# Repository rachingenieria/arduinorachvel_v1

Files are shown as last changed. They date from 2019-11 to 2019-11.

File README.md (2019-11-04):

# arduinorachvel_v1
Codigo de Velocista de JJtronics

Este repositorio contiene los archivos basicos para implementar el velocista ARDUINORACH V1

Contine:
Documentos de especificaciones

Firmware: Codigo fuente de Velocista con PID ARDUINORACH_V7
Copia de la Libreria Adafruit_SSD1306-master.zip para instalar en Arduino
como instalar: ARDUINO - Programa Menu -> Incluir Libreria -> Añadir Bliblioteca Zip

APP:Aplicativo Android
3D:Soporte de la BAteria y bomper para sensores frontal

RACHINGENIERIA

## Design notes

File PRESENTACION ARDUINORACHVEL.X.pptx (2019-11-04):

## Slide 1

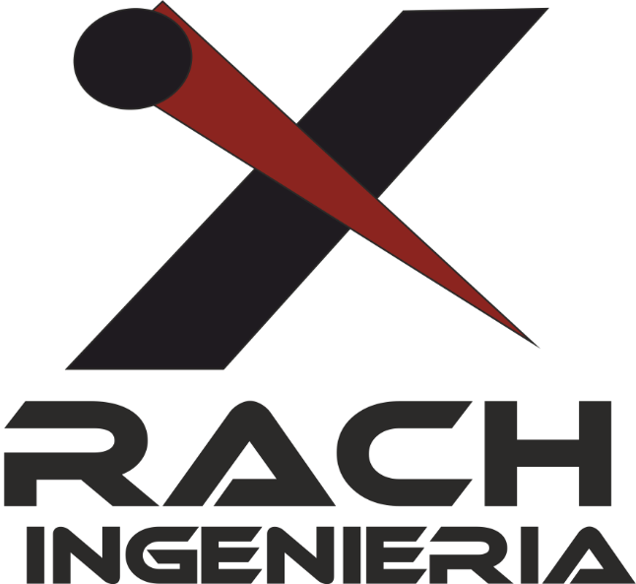
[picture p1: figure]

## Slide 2

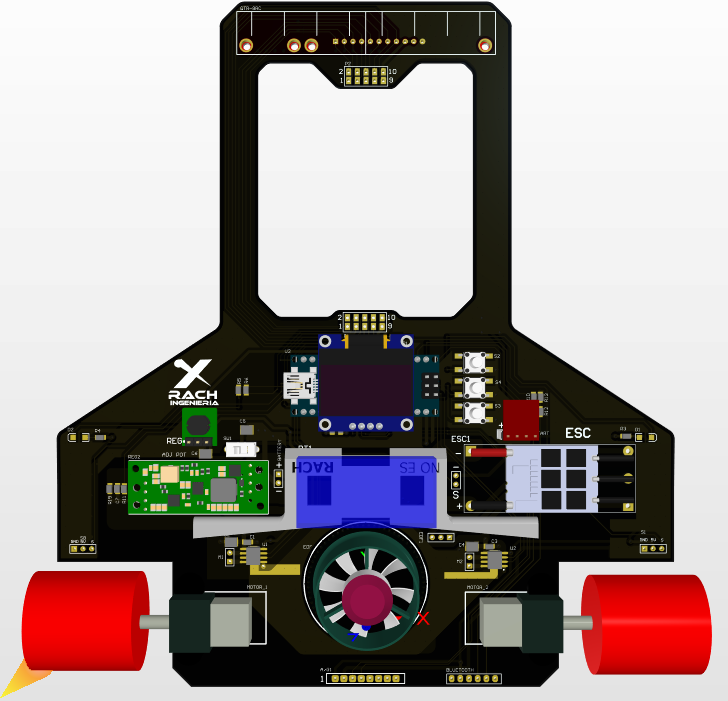
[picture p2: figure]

VELOCISTA PROFESIONAL
Descripción:
Versión Básica:
- PCB de doble marca RACHINGENIERIA
- ARDUINO NANO
- Sensores QRT8 Pololu DIGITALES
- Regulador 5V 1A
- Puente H 36V 3.6A Canal
- Micromotores
- Batería 2s o 3S
- Llantas de Poliuretano
- Rin metálico de bajo perfil
marca RACHINGEIERIA
- Puerto para modulo de Arranque
Versión Profesional (se adiciona)
- Elevador de Voltaje hasta 25V
- ESC 10A
- Turbina EDF27
- Display Oled De configuración
- Tres pulsadores de Usuario
Opcionales
- Bluetooth HC05 o HC06
- IMU (Acelerómetro y Giroscopio)
- Sensores para NATCAR o Encoder
- Extensión de sensores

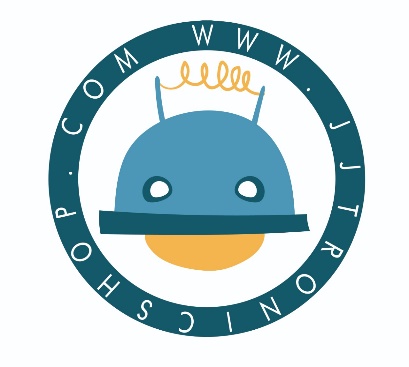
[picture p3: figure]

Cómpralo en:
www.jjtronicsshop.com

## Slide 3

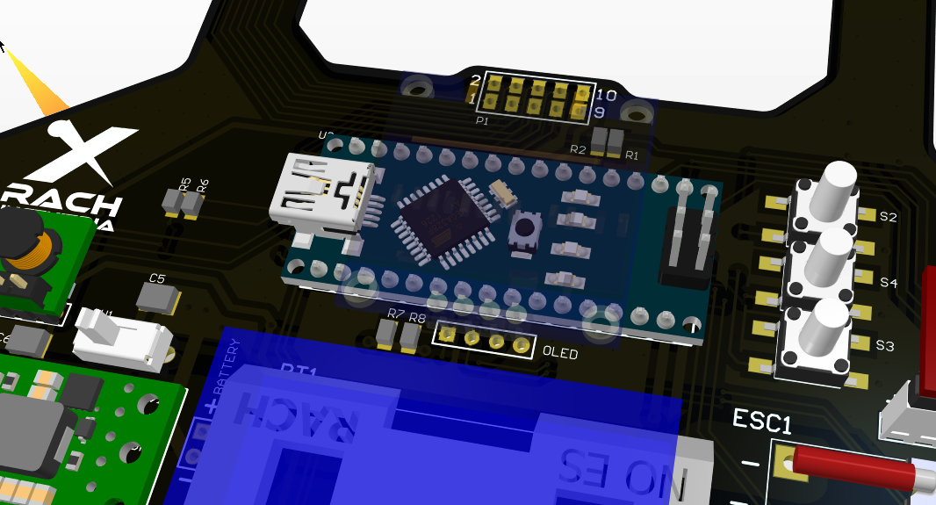
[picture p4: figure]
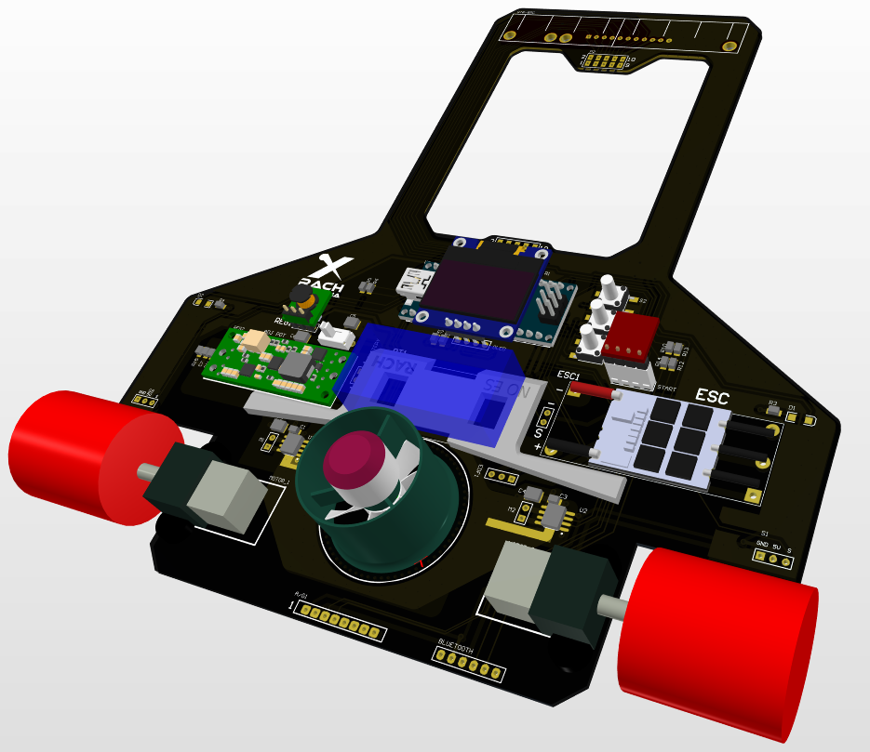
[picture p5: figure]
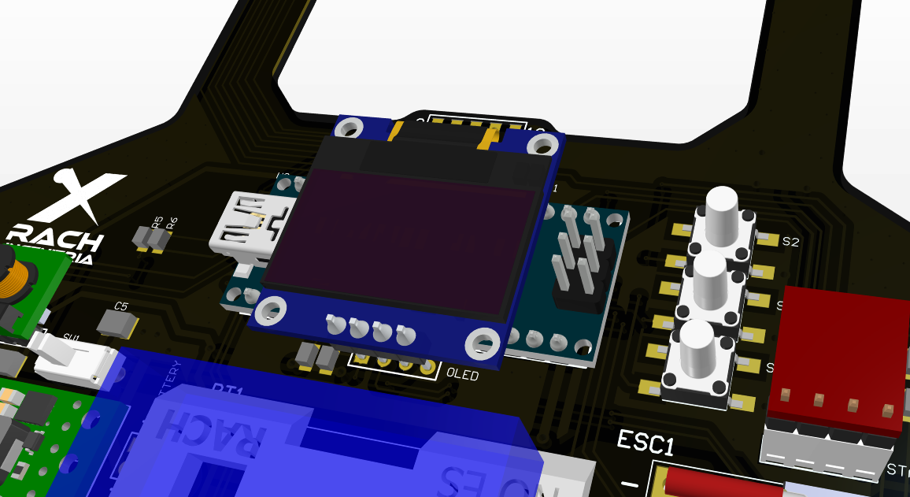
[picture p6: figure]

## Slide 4

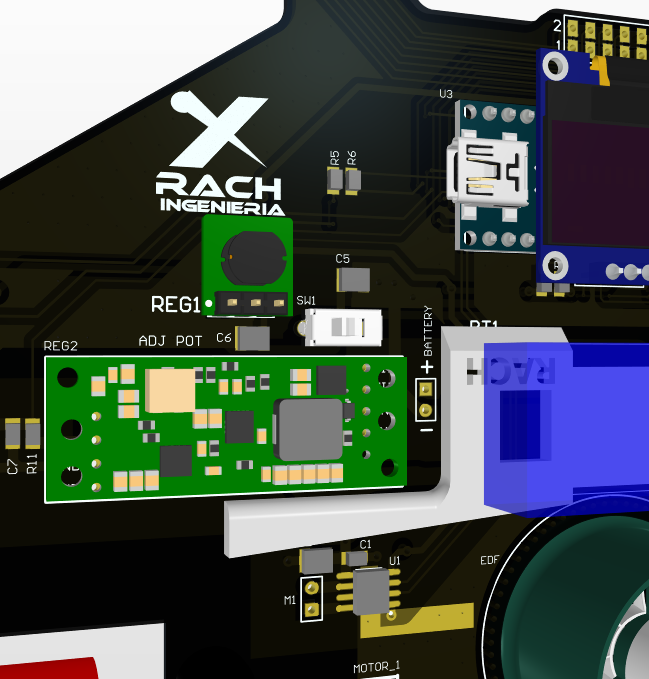
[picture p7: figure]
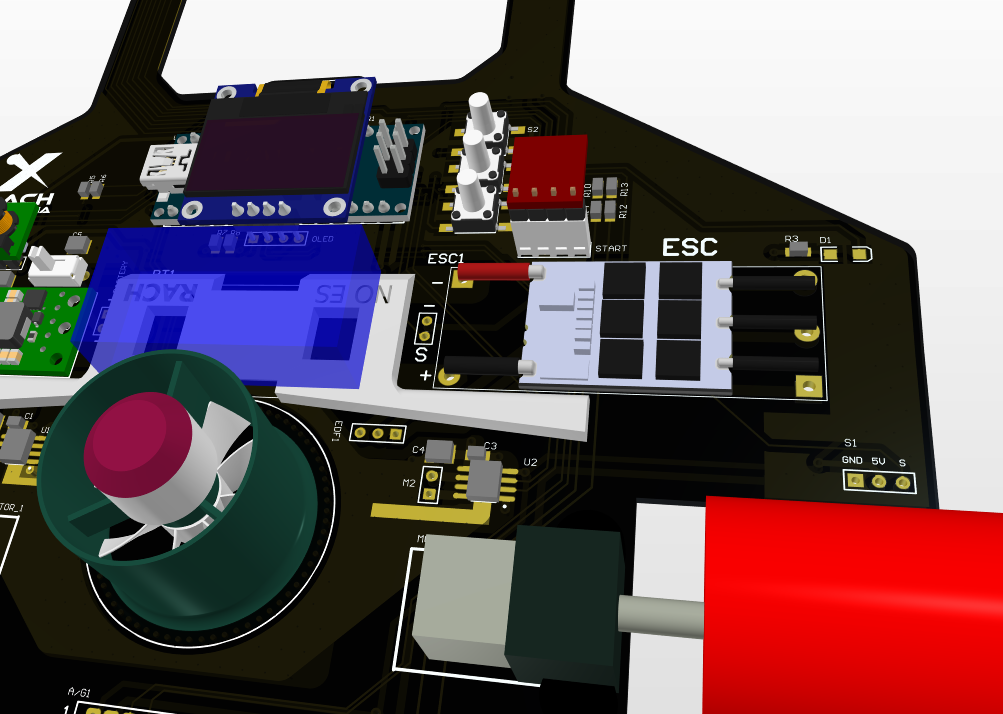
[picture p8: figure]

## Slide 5

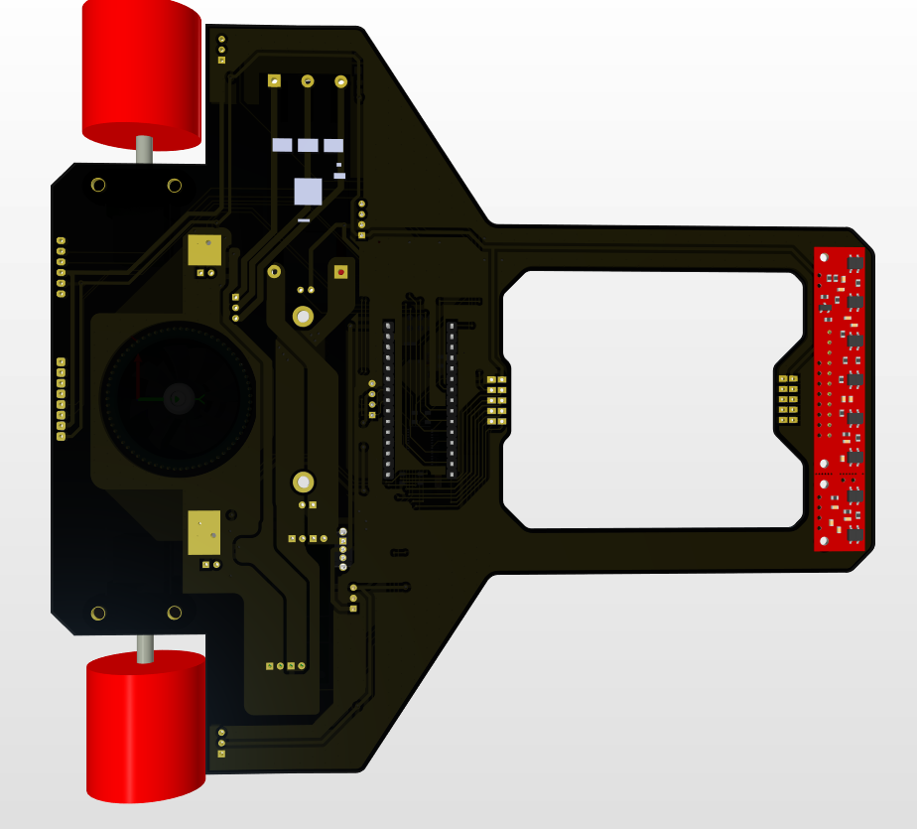
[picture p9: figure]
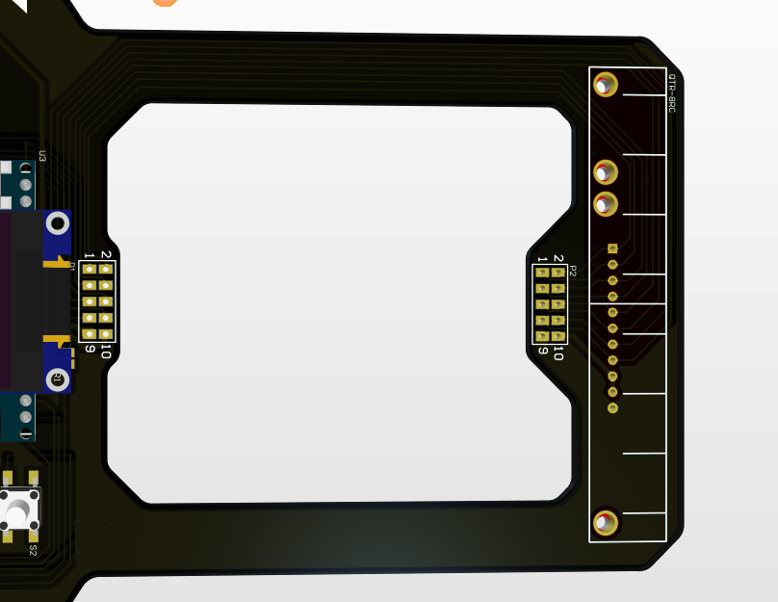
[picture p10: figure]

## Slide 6

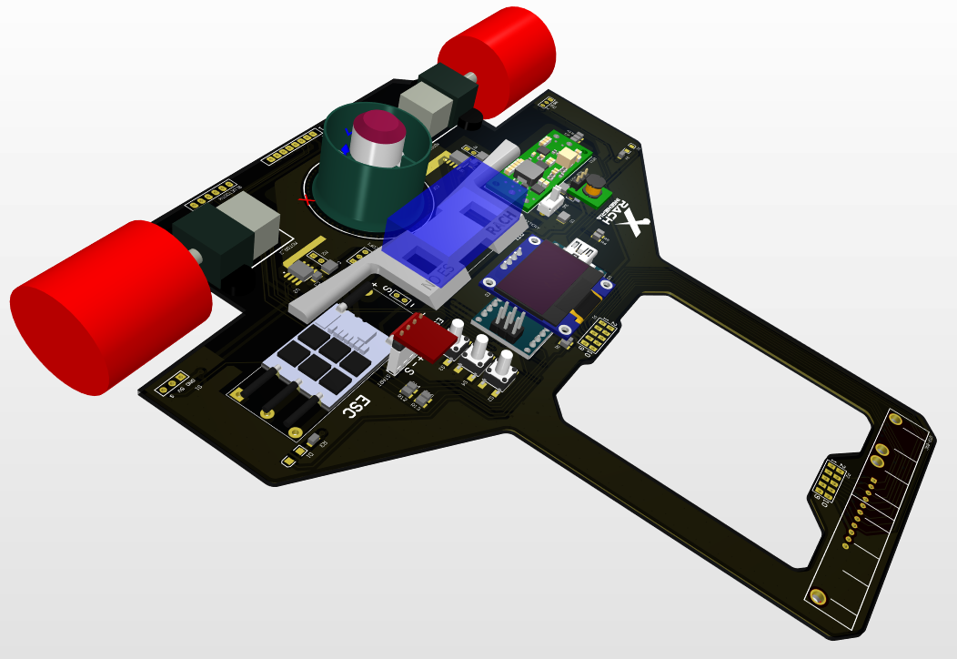
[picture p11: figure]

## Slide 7

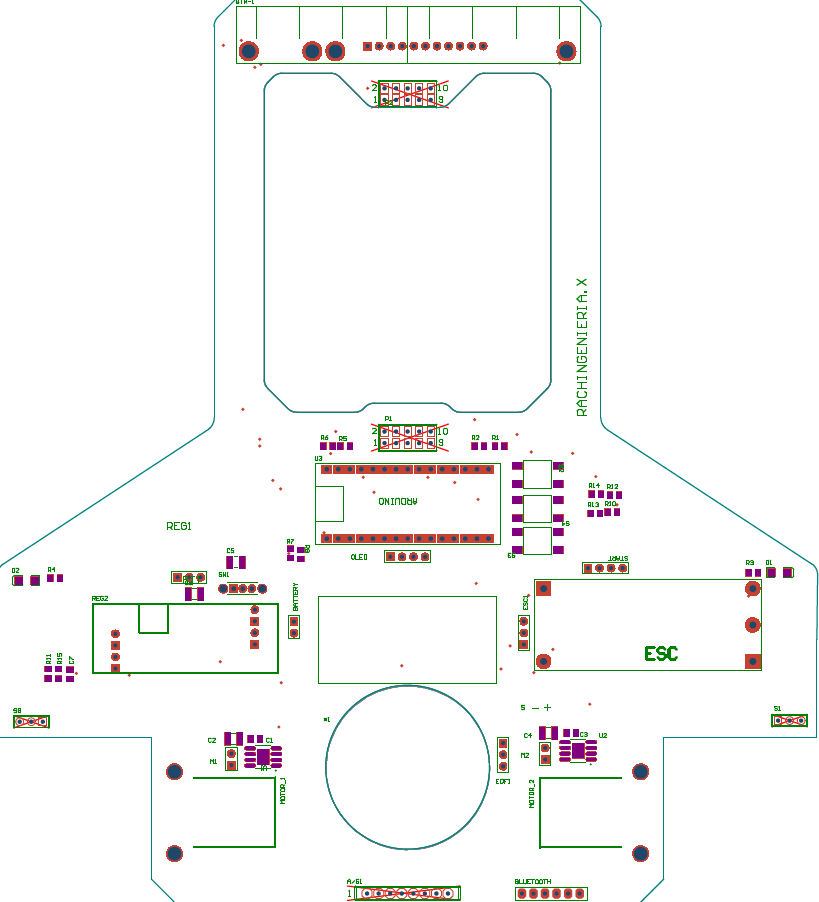
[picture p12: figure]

PARA VENTA DE PCB:
- PCB
- PLANO DE ARMADO
- CIRCUITO ESQUEMATICO
- LISTADO DE MATERIALES
- FIRMWARE ARDUIN0
- Aplicativo Android
- Soporte sensores 3D
- Bomper sensores frontales 3D

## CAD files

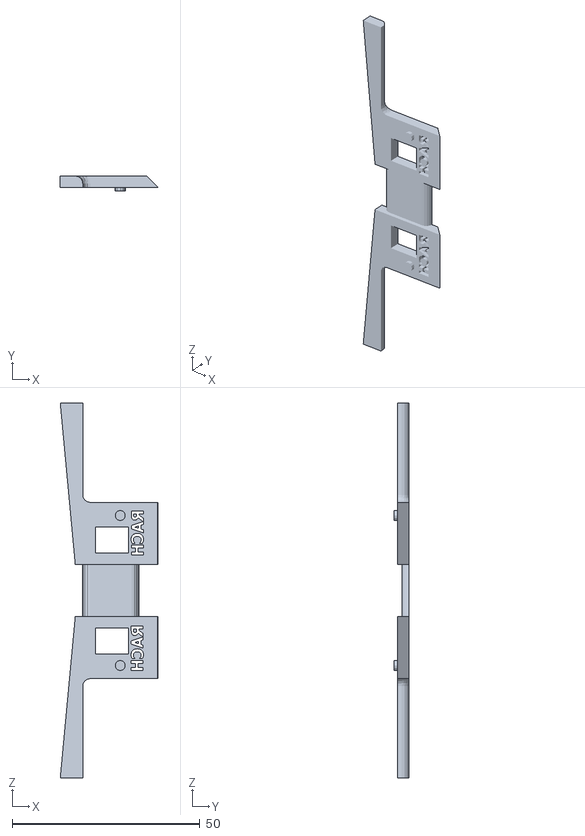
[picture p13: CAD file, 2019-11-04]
3D/soporteBat_V3.stl
26.0 x 4.00 x 100.0

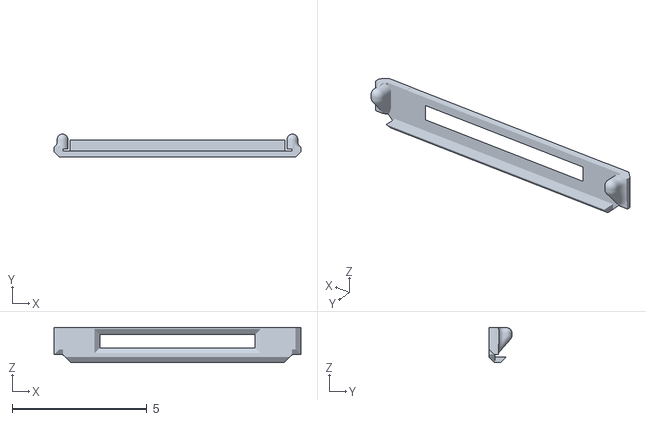
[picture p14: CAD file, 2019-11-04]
3D/PINVLECISTA.stl
9.16 x 0.849 x 1.31

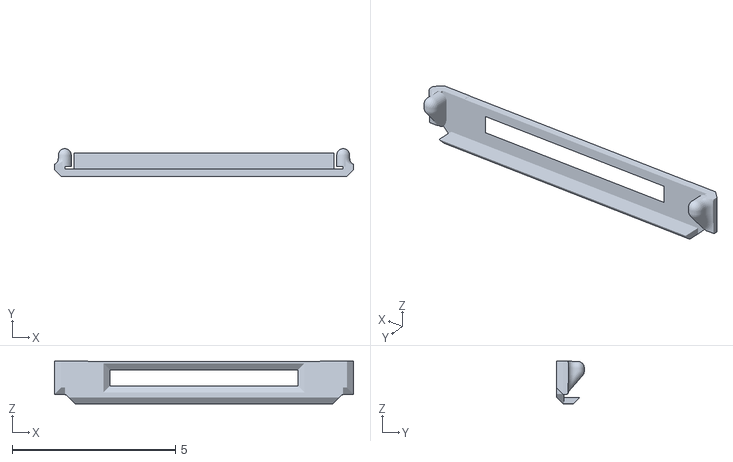
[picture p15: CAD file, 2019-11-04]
3D/PINVLECISTA.dwg.stl
9.16 x 0.849 x 1.31

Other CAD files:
3D/PINVLECISTA.ipt
3D/soporte_bat_rachx.ipt

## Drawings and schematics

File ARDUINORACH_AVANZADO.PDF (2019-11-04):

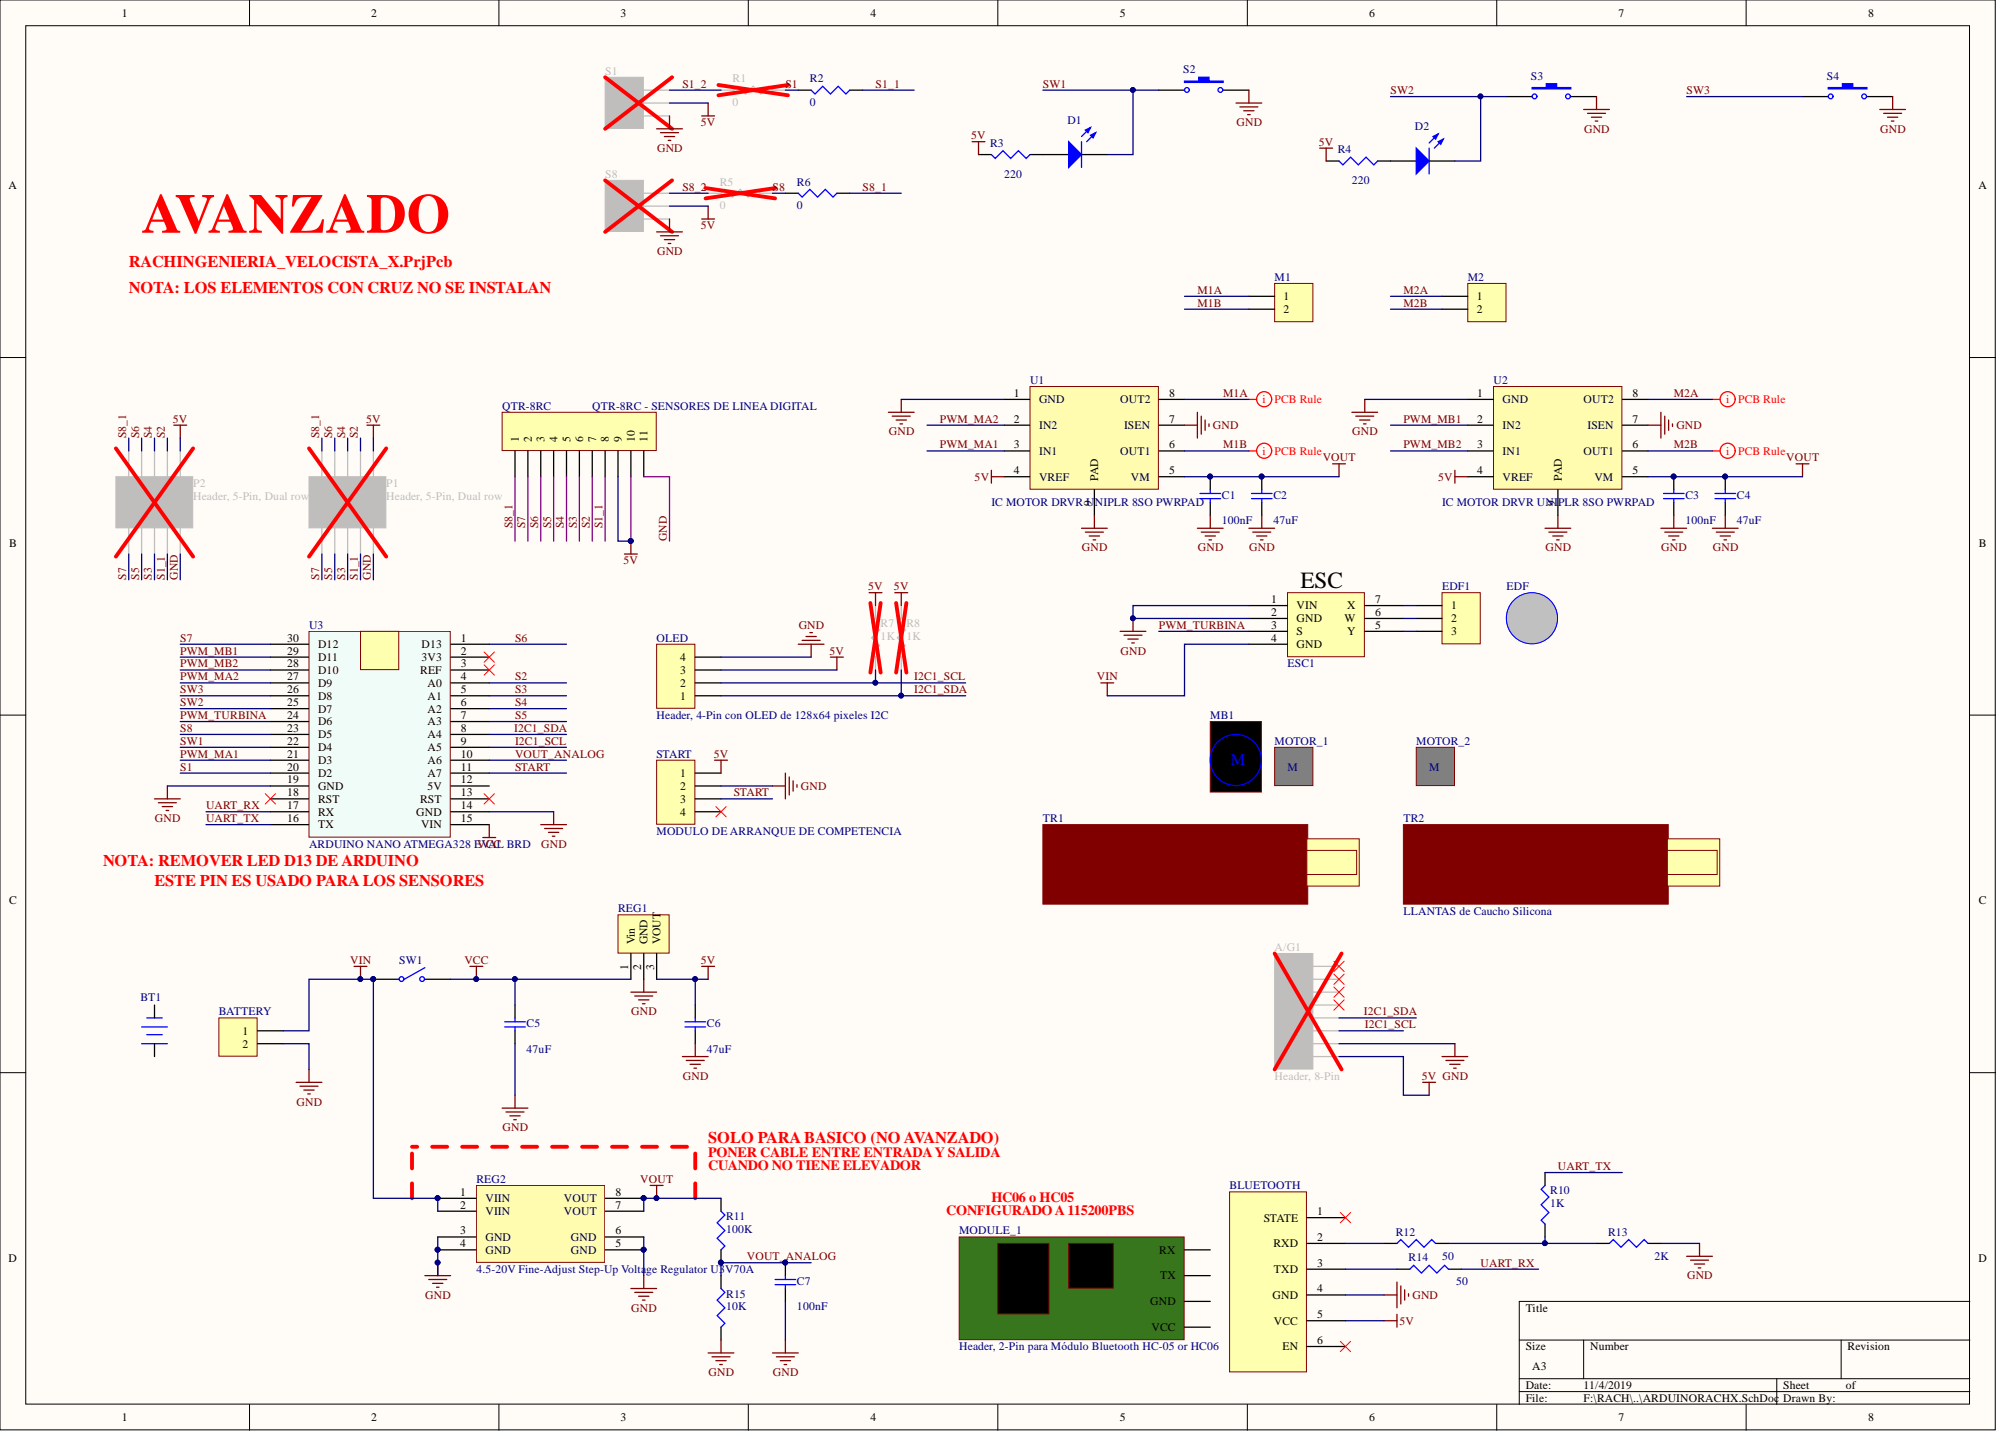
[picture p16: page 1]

RACHINGENIERIA_VELOCISTA_X.PrjPcb
NOTA: LOS ELEMENTOS CON CRUZ NO SE INSTALAN

Header, 5-Pin, Dual row

IC MOTOR DRVR UNIPLR 8SO PWRPAD

Header, 4-Pin con OLED de 128x64 pixeles I2C

ARDUINO NANO ATMEGA328 EVAL BRD

NOTA: REMOVER LED D13 DE ARDUINO

ESTE PIN ES USADO PARA LOS SENSORES

LLANTAS de Caucho Silicona

SOLO PARA BASICO (NO AVANZADO)
PONER CABLE ENTRE ENTRADA Y SALIDA
CUANDO NO TIENE ELEVADOR

4.5-20V Fine-Adjust Step-Up Voltage Regulator U3V70A

Header, 2-Pin para Módulo Bluetooth HC-05 or HC06

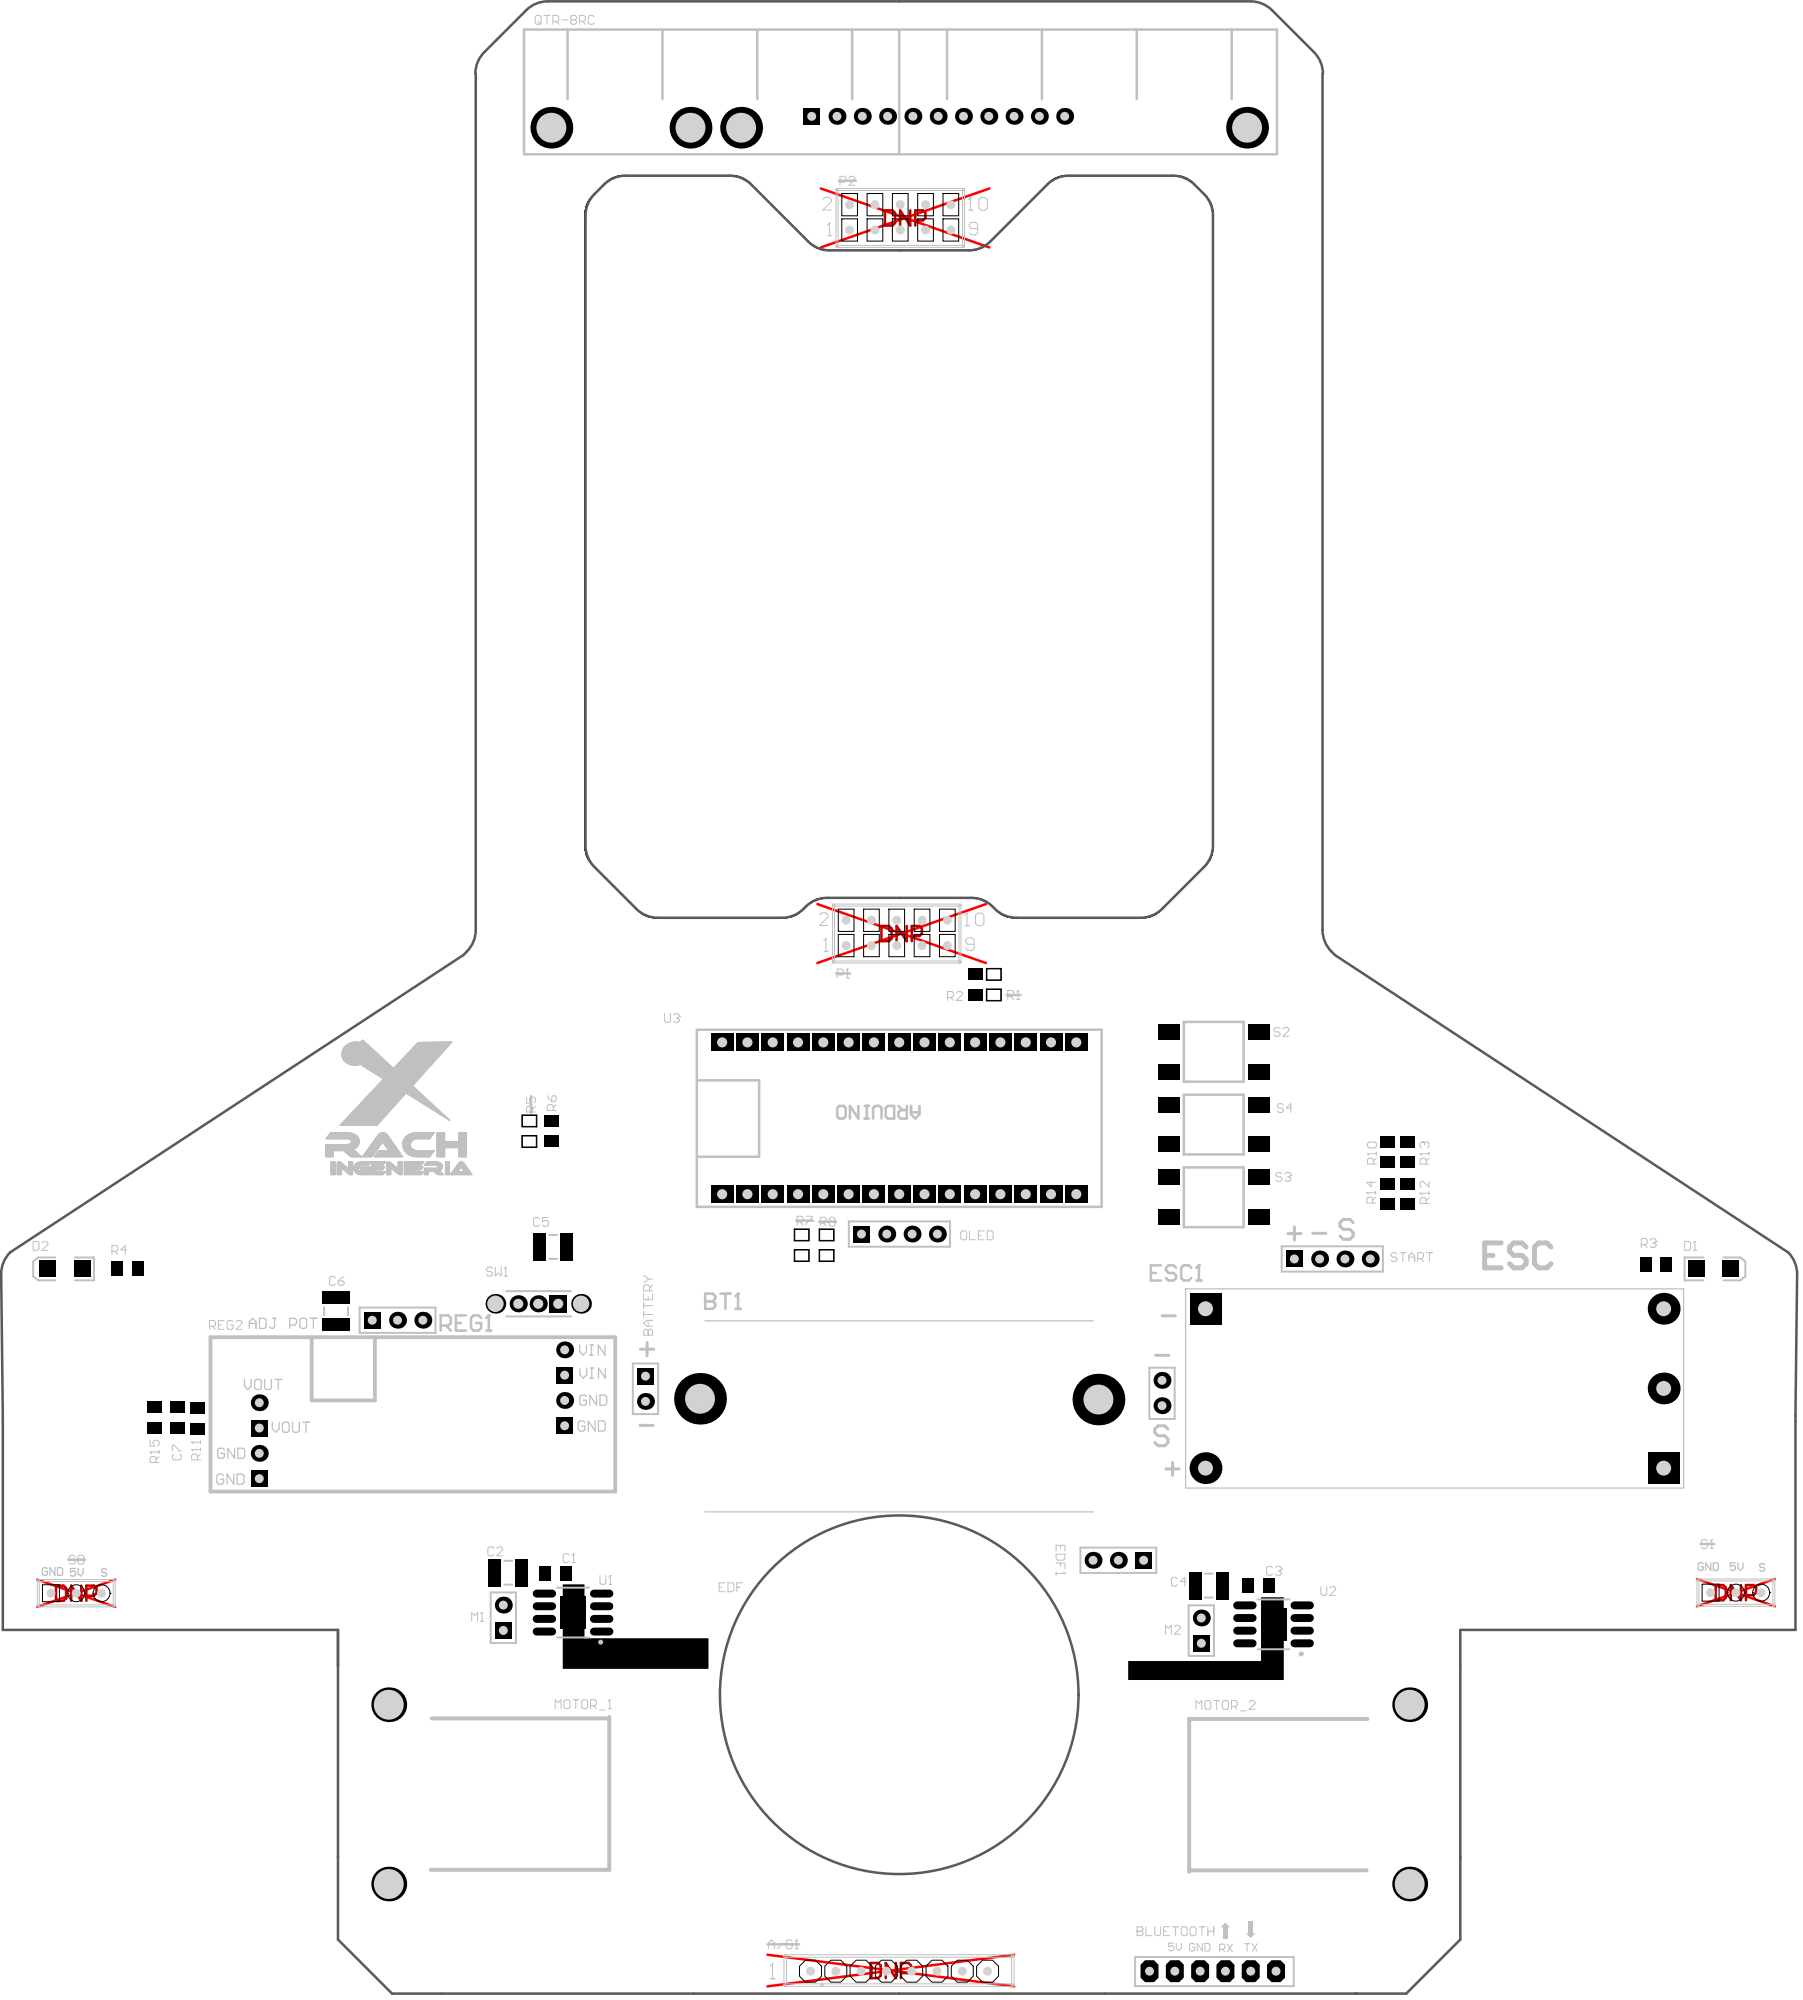
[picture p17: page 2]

Designator | Quantity | Description | Manufacturer
BATTERY | 1 | CONN HEADER VERT 2POS | Samtec Inc.
BLUETOOTH | 1 | CONN HDR 6POS 0.1 GOLD PCB | Sullins Connector Solutions
BT1 | 1 | BATERIA LIPO 2s o 3s a 300maH a 2000mAh | JJTRONICS
C1, C3, C7 | 3 | CAP CER 0.1UF 50V X7R 0805 | KEMET
C2, C4, C5, C6 | 4 | CAP CER 47UF 25V X5R 1210 | Taiyo Yuden
D1, D2 | 2 | LED RED CLEAR 1206 SMD | Visual Communications Company - VCC
EDF | 1 | EDF35 with 11000kv Motor Assembled | HobbyKing
EDF1, M1, M2 | 3 | TURBINA DE 27mm Brushless, Pines para Motor
ESC1 | 1 | SPEED CONTROLLER de 6 o mas Amperios | JJTRONICS
MB1 | 1 | Pololu Micro Metal Gearmotor Bracket Pair - Black | POLOLU
MODULE_1 | 1 | Módulo Bluetooth HC-05 or HC06 | JJTRONICS
MOTOR_1, MOTOR_2 | 2 | 10:1 Micro Metal Gearmotor HPCB 6V -3000rpm | POLOLU
OLED | 1 | Header, 4-Pin con OLED de 128x64 pixeles I2C | JJTRONICS
QTR-8RC | 1 | QTR-8RC - SENSORES DE LINEA DIGITAL | JJTRONICS
R2, R6 | 2 | RES SMD 0 OHM 1% 0.4W 0805 | Resistencia
R3, R4 | 2 | RES SMD 220 OHM 1% 0.4W 0805 | Resistencia
R10 | 1 | RES SMD 1K OHM 0.1% 1/8W 0805 | Resistencia
R11 | 1 | RES SMD 100K OHM 0.1% 1/8W 0805 | Resistencia
R12, R14 | 2 | RES SMD 50 OHM 0.05% 1/5W 0805 | Resistencia
R13 | 1 | RES SMD 2K OHM 0.1% 1/8W 0805 | Resistencia
R15 | 1 | RES SMD 10K OHM 1% 0.4W 0805 | Resistencia
REG1 | 1 | DC DC CONVERTER 5V OR -5V o 7805 | CUI Inc.
REG2 | 1 | 4.5-20V Fine-Adjust Step-Up Voltage Regulator U3V70A | POLOLU
S2, S3, S4 | 3 | PULSADOR - SWITCH TACTILE SPST-NO 0.05A 12V | E-Switch
START | 1 | MODULO DE ARRANQUE DE COMPETENCIA | JJTRONICS
SW1 | 1 | Mini Switch de dos Posiciones | C&K
TR1, TR2 | 2 | LLANTAS de Caucho Silicona | LLANTAS
U1, U2 | 2 | IC MOTOR DRVR UNIPLR 8SO PWRPAD | Texas Instruments
U3 | 1 | ARDUINO NANO ATMEGA328 EVAL BRD | Arduino

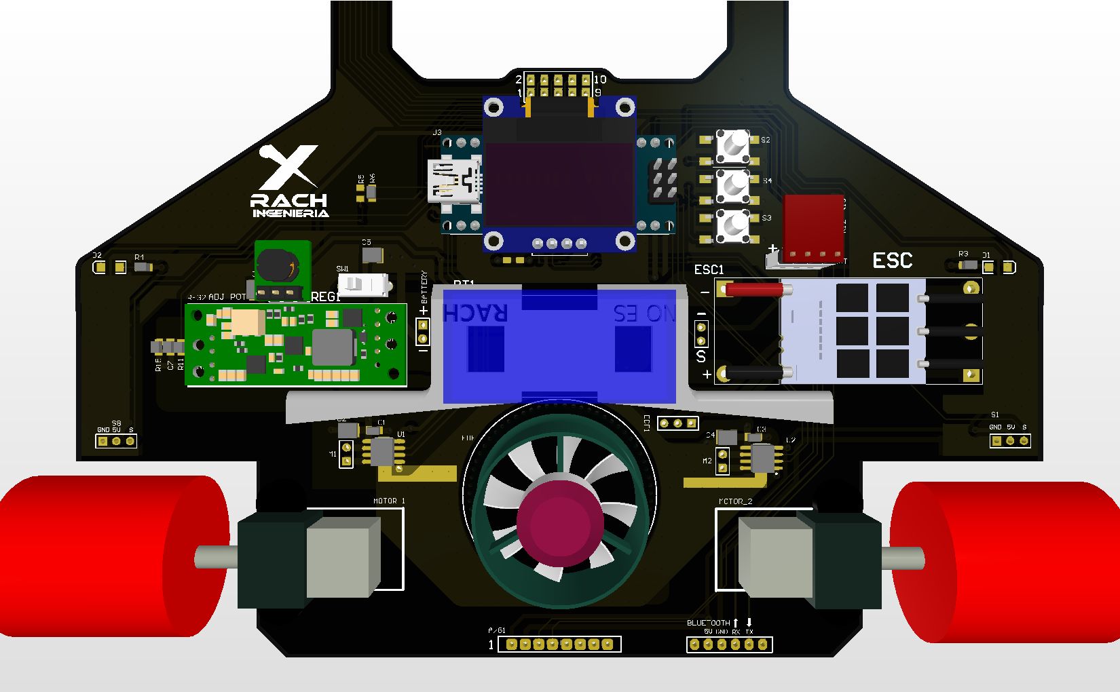
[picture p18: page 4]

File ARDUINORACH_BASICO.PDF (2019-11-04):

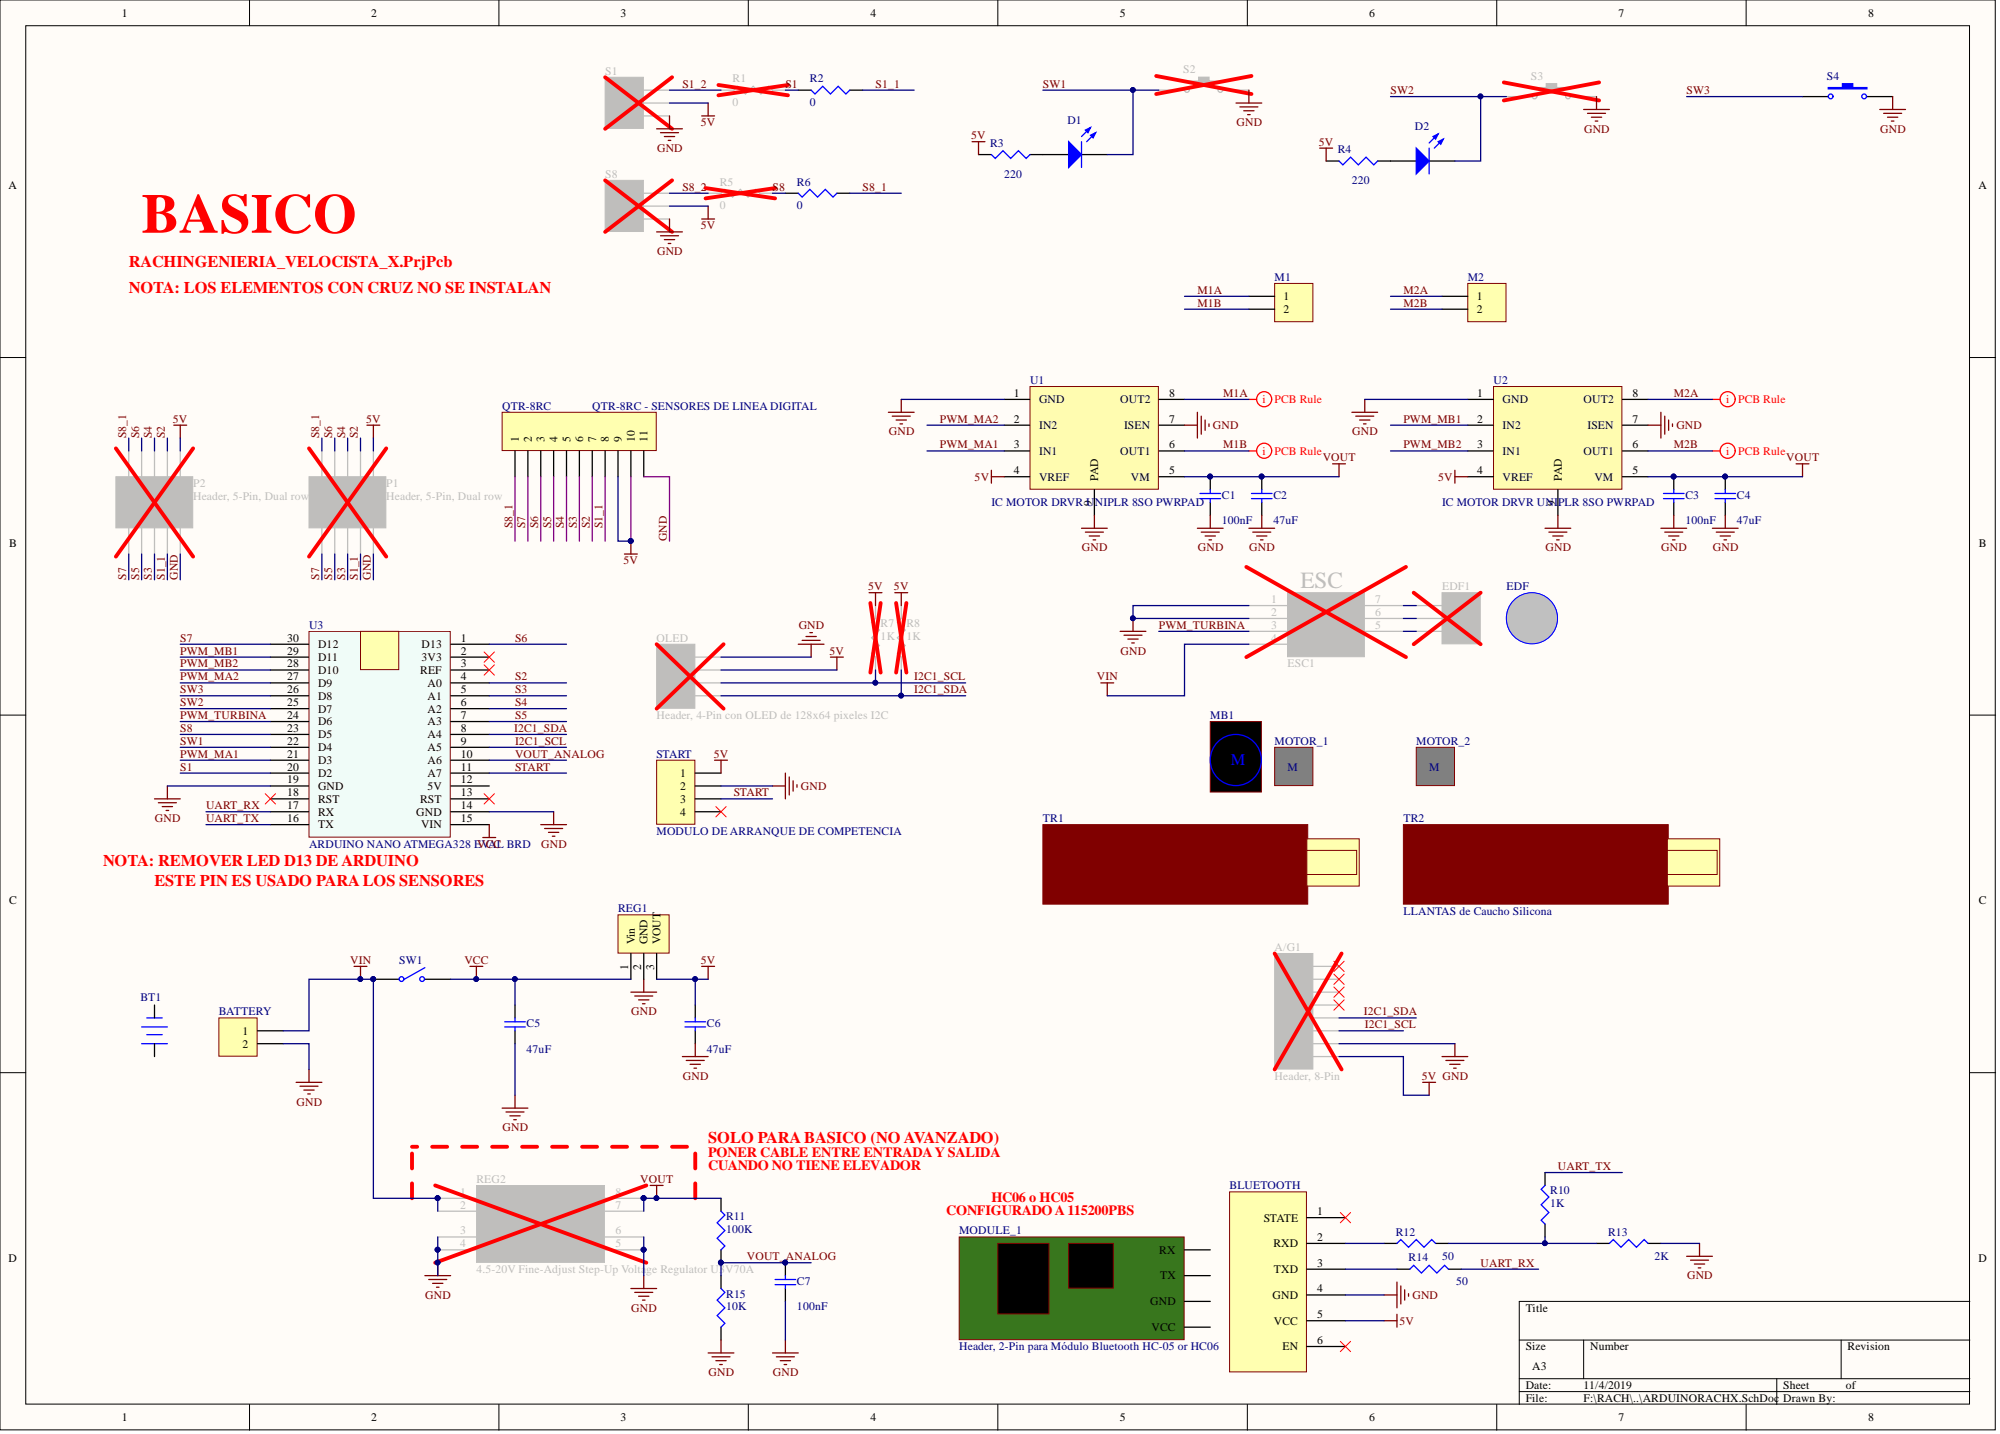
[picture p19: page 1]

RACHINGENIERIA_VELOCISTA_X.PrjPcb
NOTA: LOS ELEMENTOS CON CRUZ NO SE INSTALAN

Header, 5-Pin, Dual row

IC MOTOR DRVR UNIPLR 8SO PWRPAD

Header, 4-Pin con OLED de 128x64 pixeles I2C

ARDUINO NANO ATMEGA328 EVAL BRD

NOTA: REMOVER LED D13 DE ARDUINO

ESTE PIN ES USADO PARA LOS SENSORES

LLANTAS de Caucho Silicona

SOLO PARA BASICO (NO AVANZADO)
PONER CABLE ENTRE ENTRADA Y SALIDA
CUANDO NO TIENE ELEVADOR

4.5-20V Fine-Adjust Step-Up Voltage Regulator U3V70A

Header, 2-Pin para Módulo Bluetooth HC-05 or HC06

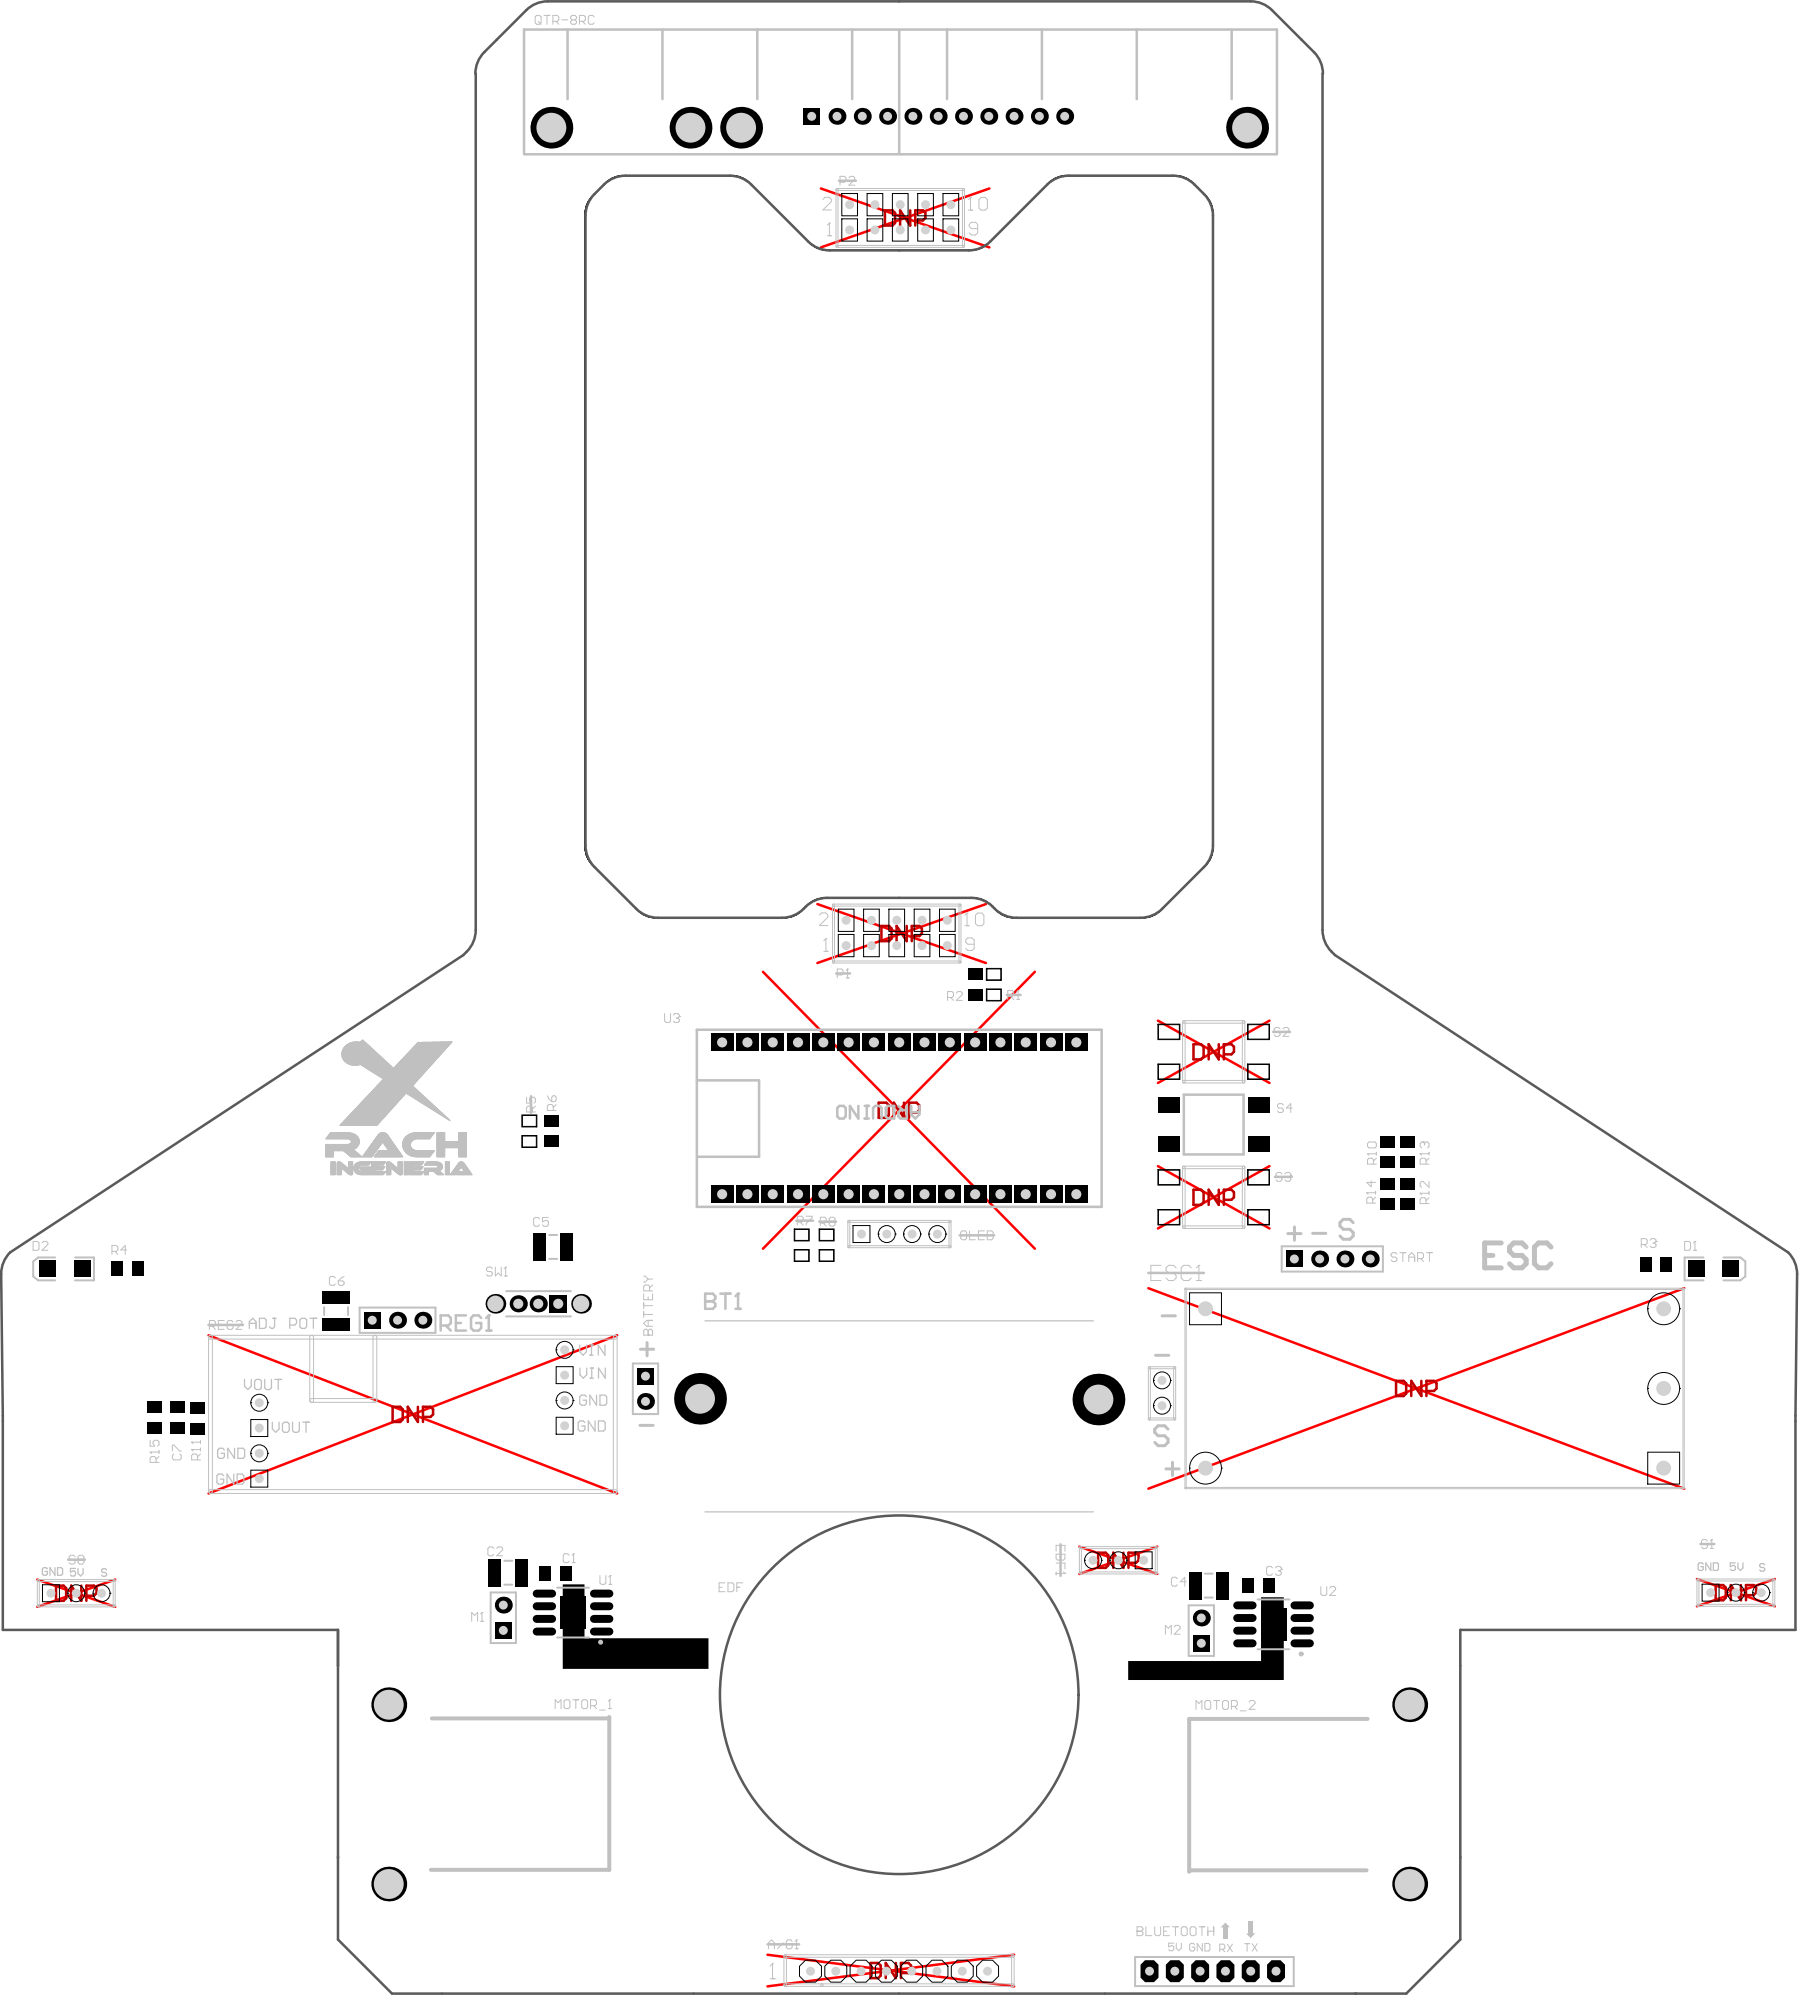
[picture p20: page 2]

Designator | Quantity | Description | Manufacturer
BATTERY | 1 | CONN HEADER VERT 2POS | Samtec Inc.
BLUETOOTH | 1 | CONN HDR 6POS 0.1 GOLD PCB | Sullins Connector Solutions
BT1 | 1 | BATERIA LIPO 2s o 3s a 300maH a 2000mAh | JJTRONICS
C1, C3, C7 | 3 | CAP CER 0.1UF 50V X7R 0805 | KEMET
C2, C4, C5, C6 | 4 | CAP CER 47UF 25V X5R 1210 | Taiyo Yuden
D1, D2 | 2 | LED RED CLEAR 1206 SMD | Visual Communications Company - VCC
EDF | 1 | EDF35 with 11000kv Motor Assembled | HobbyKing
M1, M2 | 2 | Pines para Motor
MB1 | 1 | Pololu Micro Metal Gearmotor Bracket Pair - Black | POLOLU
MODULE_1 | 1 | Módulo Bluetooth HC-05 or HC06 | JJTRONICS
MOTOR_1, MOTOR_2 | 2 | 10:1 Micro Metal Gearmotor HPCB 6V -3000rpm | POLOLU
QTR-8RC | 1 | QTR-8RC - SENSORES DE LINEA DIGITAL | JJTRONICS
R2, R6 | 2 | RES SMD 0 OHM 1% 0.4W 0805 | Resistencia
R3, R4 | 2 | RES SMD 220 OHM 1% 0.4W 0805 | Resistencia
R10 | 1 | RES SMD 1K OHM 0.1% 1/8W 0805 | Resistencia
R11 | 1 | RES SMD 100K OHM 0.1% 1/8W 0805 | Resistencia
R12, R14 | 2 | RES SMD 50 OHM 0.05% 1/5W 0805 | Resistencia
R13 | 1 | RES SMD 2K OHM 0.1% 1/8W 0805 | Resistencia
R15 | 1 | RES SMD 10K OHM 1% 0.4W 0805 | Resistencia
REG1 | 1 | DC DC CONVERTER 5V OR -5V o 7805 | CUI Inc.
S4 | 1 | PULSADOR - SWITCH TACTILE SPST-NO 0.05A 12V | E-Switch
START | 1 | MODULO DE ARRANQUE DE COMPETENCIA | JJTRONICS
SW1 | 1 | Mini Switch de dos Posiciones | C&K
TR1, TR2 | 2 | LLANTAS de Caucho Silicona | LLANTAS
U1, U2 | 2 | IC MOTOR DRVR UNIPLR 8SO PWRPAD | Texas Instruments
U3 | 1 | ARDUINO NANO ATMEGA328 EVAL BRD | Arduino

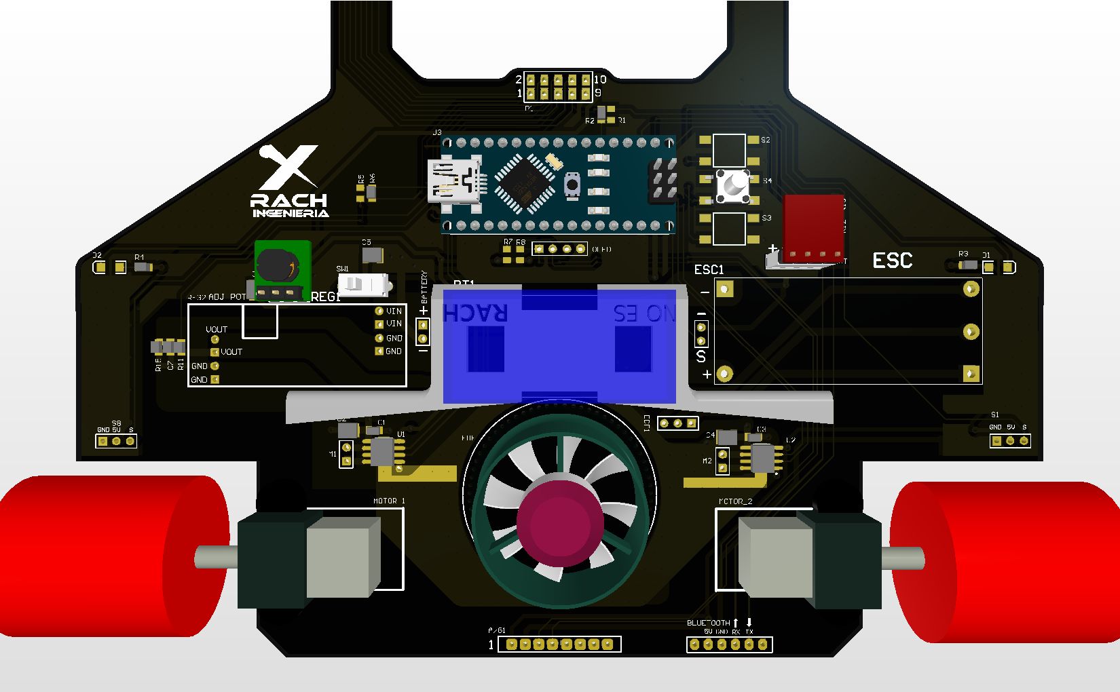
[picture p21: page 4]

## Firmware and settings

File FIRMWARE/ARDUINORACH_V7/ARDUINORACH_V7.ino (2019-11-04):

#include <stdio.h>
#include <string.h>

#include "eeprom.h"
#include "motores.h"
#include "linea.h"
#include "turbina.h"
#include "oled.h"
#include "api.h"
#include "rachvel.h"

//------------------------------------------------------------------------------------//




int error[10];
int position_line;
extern int sensores_b;
unsigned int sensorValues[NUM_SENSORS];
//--------------------------------------------------------------------------------------//
//PARAMETROS del Control del Velocista
//AQUI SE MODIFICAN LOS PARAMETROS DE COMPETENCIA
rachvel Rachvel;

 
int   VELCIDAD_MAXIMA        = 30;       //Velocidad Maxima (entre 0 y 255)
int   CTE_PROPORCIONAL       = 10;      //Constante de Control Proporcional (ente 1 y 20)
int   CTE_DERIVATIVA         = 30;      //Constante de Control Diferencia (ente 1 y 20)                                                                                                                                                                                                                                    
int   V_TURBINA              = 60;       //Velocidad Turbina en Competencia (entre 90 y 150)

//Variables para Control Adicional
float power_difference, power_difference_ext;
float power_difference_ant;
int detect_recta_ant, detect_recta;
char stat_sw = 0; 
 
void setup()
{
  int val;
    
  Eeprom_read();
  if(Rachvel.ver == FIRMWARE_VERSION)// DATOS CORRECTOS y CARGADOS
  {
    //Rachvel.setupconfig(VELCIDAD_MAXIMA,CTE_PROPORCIONAL,CTE_DERIVATIVA,CTE_INTEGRAL,V_TURBINA);
  }
  else
  {
    Rachvel.setupconfig(VELCIDAD_MAXIMA,CTE_PROPORCIONAL,CTE_DERIVATIVA,V_TURBINA); //valres por DEFECTO
    Eeprom_save();
  }


  
  pinMode(SW2_UP,INPUT);
  pinMode(SW4_ENTER,INPUT);
  pinMode(SW3_DOWN,INPUT);
  
  digitalWrite(SW2_UP, HIGH);
  digitalWrite(SW4_ENTER, HIGH);
  digitalWrite(SW3_DOWN, HIGH);
        
  Serial.begin(115200);

  pinMode(ON_RF,INPUT);

  Motor_Init();
  SetSpeeds(0,0);
  oled_init();

  int cursorz = 0;
  int menuactivo = 0;
  val = 1;

    // MENU DE CONFIGURACION
  do{
    
    int battery = analogRead(BATTERY);
    float bat = battery*(11)*5.0/1024;
    
     Oled_Api(Rachvel.vavg, Rachvel.kpg, Rachvel.kdg,  Rachvel.pmw_t, cursorz, menuactivo, bat, Rachvel.ver  );
     if(digitalRead(SW3_DOWN) == LOW)
     {
      delay(20);
            if(cursorz<4 && menuactivo == 0)
            {
               cursorz ++;
            }
            else if ( menuactivo == 1)
            {
              if(cursorz == 1)
               Rachvel.vavg = Rachvel.vavg - 1;
              if(cursorz == 2)
               Rachvel.kpg = Rachvel.kpg - 1;
             if(cursorz == 3)
               Rachvel.kdg = Rachvel.kdg - 1;
             if(cursorz == 4)
               Rachvel.pmw_t = Rachvel.pmw_t - 10;

            }
     }
     if(digitalRead(SW2_UP) == LOW)
     {
      delay(20);
             if(cursorz > 0 && menuactivo == 0)
            {
               cursorz --;
            }
            else if ( menuactivo == 1)
            {
              if(cursorz == 1)
                Rachvel.vavg = Rachvel.vavg + 1;
              if(cursorz == 2)
                Rachvel.kpg = Rachvel.kpg + 1;
             if(cursorz == 3)
                Rachvel.kdg = Rachvel.kdg + 1;
              if(cursorz == 4)
                Rachvel.pmw_t = Rachvel.pmw_t + 10;
            }
     }

     if(digitalRead(SW4_ENTER)== LOW)
     {
      delay(20);
            if( menuactivo == 0)
            {
               menuactivo = 1;
               if(cursorz == 0)
               {
                val = 0;
                Eeprom_save();
                Oled_SAVED();
               }
            }
            else if( menuactivo == 1)
            {
               menuactivo = 0;
            }
     }

     //RECIBIR DATOS POR BLUETOOTH
     Serial_command();
  }while (val);
  
  //APAGAR LOS LEDS
  pinMode(LED2, OUTPUT);
  pinMode(LED1, OUTPUT);
  digitalWrite(LED2, HIGH);
  digitalWrite(LED1, HIGH);  
  

//-------------Instrucciones para Empezar a hacer la Calibracion de Sensores--------------------------------------//

  
  //ESPERA QUE SE RETIRE EL DEDO DEL SW1
  delay(1000); 
  
  // Enciende el leds para indicar que se esta calibrando.
  digitalWrite(LED2, LOW);
  digitalWrite(LED1, LOW);
  
  //GIRA MIENTRA CALIBRA
  SetSpeeds(-450, 450);

  Reset_Calibracion();
  Rachvel.colorlinea = Calibrar_Color_Linea(sensorValues);


  int tiempo_cal = 250;
  while(tiempo_cal--)
  {
      Calibrar_Sensores(sensorValues,Rachvel.colorlinea);
      delay(5);
  }
  
 SetSpeeds(0, 0);

  // Apaga el led para indicar que se termino la calibracion.
  digitalWrite(LED2, HIGH);     
  digitalWrite(LED1, HIGH); 
 
 //stop Motors
  SetSpeeds(0,0);
    
  delay(200);
  digitalWrite(LED2, HIGH);     
  digitalWrite(LED1, HIGH);
  delay(200);
  digitalWrite(LED2, LOW);     // Parpadeo para indicar que el robot esta listo.
  digitalWrite(LED1, LOW);
  delay(200);                  // Parpadeo para indicar que el robot esta listo.
  digitalWrite(LED2, HIGH);     
  digitalWrite(LED1, HIGH);    // Parpadeo para indicar que el robot esta listo.
  delay(200);
  digitalWrite(LED2, LOW);     // Parpadeo para indicar que el robot esta listo.
  digitalWrite(LED1, LOW);
  delay(200);
  //---------------------------Fin Calibracion de Sensores----------------------------------------------------//
  
  // SECUENCIA PARA VERIFICAR SI LA CALIBRACION ESTA BIEN
  // TERMINA CUANDO SE OPRIME SW1
  val = digitalRead(SW4_ENTER);   
 do{
     val = digitalRead(SW4_ENTER);
      Oled_Sensores(sensorValues,position_line,Rachvel.colorlinea);
      position_line = Leer_linea(sensorValues,position_line ,Rachvel.colorlinea ); // leemos posicion de la linea en la variable position
  }while (val == HIGH);
  
  Oled_Calibracion();
  val = digitalRead(SW4_ENTER);  
  while (val == HIGH )
  {    
   
   position_line = Leer_linea(sensorValues,position_line ,Rachvel.colorlinea ); // leemos posicion de la linea en la variable position
   //Oled_Sensores(sensorValues,position_line);
   
 if (position_line < -20)
 {
     digitalWrite(LED2, HIGH);
     digitalWrite(LED1, LOW); 
  }
  else  if (position_line > 20 )
  {
     digitalWrite(LED2, LOW);
     digitalWrite(LED1, HIGH);    
  }
  else  
  {
   digitalWrite(LED2, HIGH);
   digitalWrite(LED1, HIGH);    
  }

  error[9]=error[8];
  error[8]=error[7];
  error[7]=error[6];
  error[6]=error[5];
  error[5]=error[4];
  error[4]=error[3];
  error[3]=error[2];
  error[2]=error[1];
  error[1]=error[0];
  error[0]=position_line;
  
  power_difference = (error[0] * Rachvel.kpg) + ((error[0] - error[2]) * Rachvel.kdg);
  SetSpeeds( -power_difference,  power_difference);

   delay(1);
   
   val = digitalRead(SW4_ENTER);
  }
  
   //---------------------------FIN DE PRUEBA DE CALIBRACION----------------------------------------------------//
 //stop Motors
  SetSpeeds(0,0);
  
  digitalWrite(LED2, LOW);
  digitalWrite(LED1, LOW);
   delay(200);
  digitalWrite(LED2, HIGH);     
  digitalWrite(LED1, HIGH);
  delay(200);
  digitalWrite(LED2, LOW);     
  digitalWrite(LED1, LOW);
  delay(200);                  
  digitalWrite(LED2, HIGH);     
  digitalWrite(LED1, HIGH);   
 
 //---------------------------CONTROL DE INICIO DE TURBINA Y TEST (OPCIONAL) ----------------------------------------------------// 


 //---------------------------LISTO PARA COMPETIR----------------------------------------------------// 
 //---------------------------SELECIONAR METODO DE INICO----------------------------------------------------//
  
// ESPERA QUE SE OPRIMA EL SW2

 digitalWrite(LED2, HIGH);
 digitalWrite(LED1, HIGH);

  Oled_TURBIA();
  Turbina_Init();
  Turbina_Start();
  

// INICIO CON MODULO REMOTO
   Oled_READY();
  
   Rachvel.start = 0; //STOP BLUETOOTH
   int rf_control = analogRead(ON_RF);

  digitalWrite(LED2, LOW); //ENCIENDE LEDS
  digitalWrite(LED1, LOW); 
  
   while(rf_control < 50 && Rachvel.start == 0 && stat_sw == 0)
   {
      rf_control = analogRead(ON_RF);
      Serial_command();
      val = digitalRead(SW4_ENTER); 
      if(val == LOW)
      {
          digitalWrite(LED2, HIGH);
          digitalWrite(LED1, HIGH);
          delay(1000);
          digitalWrite(LED2, HIGH);
          digitalWrite(LED1, LOW);
          delay(1000);
          digitalWrite(LED2, LOW);
          digitalWrite(LED1, HIGH);
          delay(1000);
          digitalWrite(LED2, HIGH);
          digitalWrite(LED1, HIGH);
          delay(1000);
          digitalWrite(LED2, LOW);
          digitalWrite(LED1, LOW);
          delay(999);
          stat_sw =  1;
      }
   }


  if(Rachvel.start == 0xFF) // MODULO CONECTADO PERO ARRANCA POR SW
  {
      stat_sw =  1; //NO PARA POR MODULO
  }
  
  if(rf_control > 50) // MODULO CONECTADO PERO ARRANCA POR SW
  {
    stat_sw =  0; //NO PARA POR MODULO
  }

   Rachvel.start = 0xFF; //START BLUETOOTH

  
  Oled_GO();


// Si se necesitan 5 Segundos
//delay(5000); 

//INICIO DE TURBINA
Turbina_Vel(Rachvel.pmw_t);
 
  
}
 
void loop()
{
 
//APAGADO POR MODULO REMOTO
   int rf_control = analogRead(ON_RF);
   if (rf_control < 50 && stat_sw == 0)
   {
       Turbina_Vel(0); 
       SetSpeeds(0, 0);
       Oled_STOP();
       while(1)
       {
          digitalWrite(LED2, HIGH);
          digitalWrite(LED1, HIGH);
          delay(500);
          digitalWrite(LED2, LOW);
          digitalWrite(LED1, LOW);
          delay(500);
        
        }
   } // STOP ROBOT
   
  position_line = Leer_linea(sensorValues,position_line ,Rachvel.colorlinea ); // leemos posicion de la linea en la variable position

   
 if (position_line < -20)
 {
     digitalWrite(LED2, HIGH);
     digitalWrite(LED1, LOW); 
  }
  else  if (position_line > 20 )
  {
     digitalWrite(LED2, LOW);
     digitalWrite(LED1, HIGH);    
  }


  error[9]=error[8];
  error[8]=error[7];
  error[7]=error[6];
  error[6]=error[5];
  error[5]=error[4];
  error[4]=error[3];
  error[3]=error[2];
  error[2]=error[1];
  error[1]=error[0];
  error[0]=position_line;

 detect_recta_ant = detect_recta;
 detect_recta = 1;

      for(int i=0 ; i<10; i++)
      {
        if( error[i] > 8 || error[i] < -8)
        {
          detect_recta = 0;
        }

      }

      if(detect_recta) //es RECTA
      {
         digitalWrite(LED2, HIGH);
         digitalWrite(LED1, HIGH);
      }
      else //ES CURVA
      {
         if(detect_recta_ant) //ENTRA A CURVA
         {
             digitalWrite(LED2, LOW);
             digitalWrite(LED1, LOW);
             SetSpeeds(-900, -900);
             delay(5);
         }
      }


  int vavg= Rachvel.vavg;
  vavg = vavg*10;
  power_difference = (error[0] * Rachvel.kpg) + ((error[0] - error[4]) * Rachvel.kdg);

  if( Rachvel.start )
  {
     SetSpeeds(vavg  - power_difference, vavg +  power_difference);
     Turbina_Vel(Rachvel.pmw_t);
  }
  else
  {
     SetSpeeds(0, 0);
     Turbina_Vel(0); 
  }
//SERIAL STOP
Serial_command();

   delay(1);
}

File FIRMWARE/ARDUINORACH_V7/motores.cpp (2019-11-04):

#include <arduino.h>
#include "motores.h"

static int motord, motori;

void Motor_Init(void)
{
  pinMode(MOTORD_AIN1, OUTPUT);
  pinMode(MOTORD_AIN2, OUTPUT);
  pinMode(MOTORI_AIN1, OUTPUT);
  pinMode(MOTORI_AIN2, OUTPUT);

  TCCR2A =   B00000011;  // Fast PWM MODE - OCA DISCONETED
  TCCR2B =  (TCCR2A & B11110111) ;  
  
  TIMSK2 = (TIMSK2 & B11111000) | 0x07;
}

void SetSpeeds(int mi,int md)
{
 motord = md/4;
 motori = mi/4 ;

 int motor_derecho = md/4;
 int motor_izquierdo = mi/4;
 
 if(motor_derecho > 0)
  {
    
     if(motor_derecho>255)
         {
            motor_derecho = 255;
         }
     motor_derecho = 255 - motor_derecho;    
     OCR2B = motor_derecho;
  }
  else if(motor_derecho < 0)
    {
      
      if(motor_derecho<-255) //LIMITE GIRO ATRAS
         {
            motor_derecho = -255;
         }
         
     motor_derecho = 255 + motor_derecho;
     OCR2B = motor_derecho;
  }
 
 
 
  if(motor_izquierdo > 0)
  { 
    if(motor_izquierdo>255)
    {
      motor_izquierdo = 255;
    }
    motor_izquierdo = 255 - motor_izquierdo;
    OCR2A = motor_izquierdo;
  }
  else if (motor_izquierdo < 0)
    {
       if(motor_izquierdo<-255)
         {
            motor_izquierdo = -255;
         }
      motor_izquierdo = 255 + motor_izquierdo;     
      OCR2A = motor_izquierdo;
  }
  
}

ISR(TIMER2_OVF_vect){
    digitalWrite(MOTORI_AIN1, HIGH);
    digitalWrite(MOTORI_AIN2, HIGH);
    digitalWrite(MOTORD_AIN1, HIGH);
    digitalWrite(MOTORD_AIN2, HIGH);
}

ISR(TIMER2_COMPA_vect){
  
 if(motori > 0)
  { 
     digitalWrite(MOTORI_AIN1, LOW);
  }
  else if(motori < 0) 
  {
     digitalWrite(MOTORI_AIN2, LOW);
  }
}
 
ISR(TIMER2_COMPB_vect){
   if(motord > 0)
  { 
     digitalWrite(MOTORD_AIN1, LOW);
  }
  else if(motord < 0) 
  {
     digitalWrite(MOTORD_AIN2, LOW);
  }
}

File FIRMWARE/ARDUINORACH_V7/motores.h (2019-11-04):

#define MOTORD_AIN1    11   
#define MOTORD_AIN2    10  

#define MOTORI_AIN1    9
#define MOTORI_AIN2    3

void Motor_Init(void);
void SetSpeeds(int,int);
